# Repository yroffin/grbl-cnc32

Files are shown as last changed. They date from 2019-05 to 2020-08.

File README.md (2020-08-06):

# grbl-cnc32

Simple controller for my RS-CNC32, this Grbl controller runs on a ESP32.

Swagger here : https://yroffin.github.io/grbl-cnc32/swagger-ui

Work based on https://github.com/mstrens/grbl_controller_esp32.

Thanks to https://github.com/mstrens for his initial work.

dependencies
* webui i angular 2.x based (with no CORS enabled).
* ArduinoJson and TFT_eSPI_ms on firmware part

# features and todos

## feature

* firmware
  * move your tools on each axis with TFT or a nunchuk
  * order homing, set coordinate ...
  * get usefull statistics (logs, GRBL output)
  * mount a SDCARD and print your GCODE files
  * handle GRBL admin order (reset, alarm ...)
  * ntp connect to obtain local time
  * wifi and rest server support
    * all configuration handle by api rest (read and write)
    * try a list a access point
  * local serial simulation for developpment
* webui
    * all feature can be reach from this ui
    * graphic positionning
    * load stl files
    * upload gcode files

## todo

* edit gcode directly a sdcard

# api

This firmware is API REST based.

## config.json resource (see bellow in setup bloc)

See https://yroffin.github.io/grbl-cnc32/swagger-ui

# setup and more

see [INSTALL.md](INSTALL.md)

# Hardware and software

## Hardware

To implement this project you need:
- an ESP32 development board and
- a display module combining 3 components:
  - a touch screen 320 X 240 a ILI9341 (display controller),
  - a XPT2046 (control the touch panel) and
  - a SD card support
  
Note: this configuration uses the ILI9341 with 4 wires (CLK, MOSI, MISO and CD).

Currently, this project works only with a TFT having a ILI9341 chip, a resolution of 320X240 and XPT2046 chip for the touch screen. If you are using another display, you should change the code yourself.

## Software

This project compiles in Arduino IDE but it requires:
- to add in Arduino IDE the software that support ESP32. The process is explained e.g. in this link
	https://randomnerdtutorials.com/installing-the-esp32-board-in-arduino-ide-windows-instructions/
 
Take care that if you do not use my configuration, you can have:
-  to edit the file User_setup.h included in the TFT_eSPI_ms folder.
   This file specify the type of display controller and the pins being used by the SPI, the display and the touch screen chip select.
-  to edit the file config.h from this project in order to specify some pins being used (e.g. the chip select for the SD card reader)
  
Note: the pins used for the SPI signals (MOSI, MISO, SCLK) are currently hardcoded.
Please note that many ESP32 pins are reserved and can't ne used (reserved for bootup, for internal flash, input only,...).
See doc on ESP for more details.

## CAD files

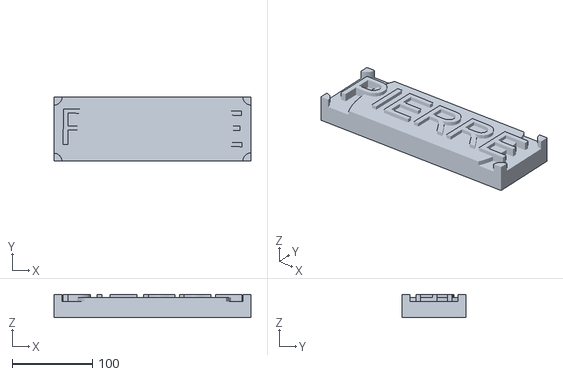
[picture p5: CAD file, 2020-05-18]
ui/src/assets/test.stl
245.2 x 79.9 x 29.0

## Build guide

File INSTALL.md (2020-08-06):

# grbl-cnc32

## Setup arduino

Simply compil and deploy arduino part (vscode plugin is very cool for that)
* see firmware/grbl-cnc32.ino

## Setup ui

In ui folder, simply run npm build (pre-requisite node)

```shell
npm run build
```

And copy dist folder on sdcard in /static

## Setup config

Config sample files are stored in config folder

Simply add a first i18n_enUS.json, i18n_frFR.json on your root SDCARD (it can be updated by API after)

Simply add a first config.json (*) on your root SDCARD (it can be updated by API after)

* remove key tft to force re-calibration

```json
{
    "sys": {
        "lang": "/i18n_enUS.json"
    },
    "wifi": [
        {
            "ssid": "<your SSID>",
            "pass": "<your password>"
        }
    ],
    "tft": {
        "calibrate": [386, 3530, 220, 3627, 7]
    },
    "grbl": {
        "emulate": false
    },
    "nunchuk": {
        "calibrate": {
            "x": 100,
            "y": 100
        }
    },
    "commands": {
        "cmd01": [
            "Line 1",
            "Line 2",
            "..."
        ]
    }
}
```

## wifi bloc

setup your wifi access :
* an array of SSID/PASS to scan

## tft bloc

setup your tft :
* with a 5 values array of tft calibration

## grbl bloc

setup your grbl :
* emulate is a boolean to setup a mock behaviour

## nunchuk bloc

setup your nunchuk :
* calibrate contain 2 fields x and y to setup nunchuk calibration

## commands bloc

setup your commands :
* a lines array for the command

## fingerprint bloc

timestamp
* uTime le last update time in unix second
* fTime le last update time

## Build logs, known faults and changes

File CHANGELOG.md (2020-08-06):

# 1.00

Official 1.00 version after one year of work

# 0.86

Rework command api
- add tryWrite
- add forceWrite
- and reset

# 0.85

Add GRBL file transfer

# 0.84

Write from api (wifi) on console
Add ui

# 0.84

Add webserver feature

# 0.83

Add script capacity in commands

# 0.82

Add command panel
Only handle file in file panel (no more command)
- remove switch
- only print files
Update default calibrate data
Add new widget
- buttonCmd to launch command
- and action control on dialog (for use dialog on other part)

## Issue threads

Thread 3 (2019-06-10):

Enhancement

yroffin, 2019-06-10:
Quelques retours sur ce que je vois: 'up' et 'down' pour Z c'est logique, mais pas pour Y où j'aurais mis 'front' et 'back' (ou un truc du genre, je ne suis pas super bon en anglais).
'Pas'= c'est un mot français au milieu de mots anglais, je trouve ça bizarre, 'step' à la limite (faut qu'un bilingue passe par là, parce que je ne suis pas sûr là non plus).

yroffin, 2019-06-10:
Quelques retours sur ce que je vois: 'up' et 'down' pour Z c'est logique, mais pas pour Y où j'aurais mis 'front' et 'back' (ou un truc du genre, je ne suis pas super bon en anglais).
'Pas'= c'est un mot français au milieu de mots anglais, je trouve ça bizarre, 'step' à la limite (faut qu'un bilingue passe par là, parce que je ne suis pas sûr là non plus).

Closed 2019-06-10.

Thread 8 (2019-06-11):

Work on fusion 360 postprocessor

yroffin, 2019-06-11:
il faut faire son propre post-processor pour corriger les nombreuses erreurs qui sont:
-le %
-le gcode de changement d'outil
-le gcode pour éteindre la broche
-qui inclut le code de Carbide pour avoir des ronds corrects

Closed 2020-05-10.

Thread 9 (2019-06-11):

File display

yroffin, 2019-06-11:
Essai à blanc d'un fichier gcode de la version 8 bits, fonctionnement apparemment OK
Les fichiers .nc de la carte SD n'apparaissent pas dans la liste

yroffin, 2019-06-12:
I've checked ... no bug for me

Closed 2020-05-10.

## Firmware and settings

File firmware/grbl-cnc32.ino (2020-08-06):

#include "TFT_eSPI_ms/TFT_eSPI.cpp" // setup file has to be edited for some parameters like screen device, pins

#include "vars.hpp"
#include "widget.hpp"
#include "evt-ctrl.hpp"
#include "wifi-ctrl.hpp"
#include "storage-ctrl.hpp"
#include "grbl-ctrl.hpp"
#include "i18n-ctrl.hpp"
#include "nunchuk-ctrl.hpp"
#include "json-config.hpp"

void setup()
{
    // prepare TFT
    TFT_Screen::instance()->prepare();

    // JsonConfigCtrl controller
    JsonConfigCtrl::instance()->setup();

    // I18nCtrl controller
    I18nCtrl::instance()->setup();

    // screen controller
    log_i("%s", I18nCtrl::instance()->translate(I18N_STD, "INI", "TFT_Screen"));
    TFT_Screen::instance()->init();

    // event controller
    TFT_Screen::instance()->outputConsole(I18nCtrl::instance()->translate(I18N_STD, "INI", "EvtCtrl"));
    EvtCtrl::instance()->init();

    // storage controller
    TFT_Screen::instance()->outputConsole(I18nCtrl::instance()->translate(I18N_STD, "INI", "StorageCtrl"));
    StorageCtrl::instance()->init();

    // wifi controller
    TFT_Screen::instance()->outputConsole(I18nCtrl::instance()->translate(I18N_STD, "INI", "WifiCtrl"));
    WifiCtrl::instance()->setup();

    // grbl controller
    TFT_Screen::instance()->outputConsole(I18nCtrl::instance()->translate(I18N_STD, "INI", "GrblCtrl"));
    GrblCtrl::instance()->setup();

    // NunchukCtrl controller
    TFT_Screen::instance()->outputConsole(I18nCtrl::instance()->translate(I18N_STD, "INI", "NunchukCtrl"));
    NunchukCtrl::instance()->setup();
}

void loop()
{
    // capture events
    EvtCtrl::instance()->capture();
    // capture events
    NunchukCtrl::instance()->loop();
    // init wifi, capture http request
    WifiCtrl::instance()->loop();
    // flush grbl events
    GrblCtrl::instance()->loop();
    // dispatch event
    EvtCtrl::instance()->dispatchPrimaryEvents();
    // dispatch event (until any)
    for (; EvtCtrl::instance()->dispatchSecondaryEvents();)
        ;
    // render
    TFT_Screen::instance()->render();
    TFT_Screen::instance()->setInvalidated(false);
    // printing
    GrblCtrl::instance()->spool();
    // flush events
    EvtCtrl::instance()->flush();
}

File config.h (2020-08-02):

#ifndef _config_h
#define _config_h

// Note: SPI is currently hardcoded for using following pins
// MOSI=13, MISO=12, SCK=14
// Those are used for the display, the touch panel and the SD card reader.

#define TFT_LED_PIN 25 // pin connected to led of lcd; pin has to be high to set led ON

// other TFT pins are defined in tft_espi User_Setup.h file

#define SD_CHIPSELECT_PIN 26 //5  // pin for SD card selection // to change probably

// pins for Serial to GRBL (it uses Serial2 UART)
#define SERIAL2_RXPIN 16
#define SERIAL2_TXPIN 17

// select color between (or define your own)
// TFT_BLACK       0x0000      /*   0,   0,   0 */
// TFT_NAVY        0x000F      /*   0,   0, 128 */
// TFT_DARKGREEN   0x03E0      /*   0, 128,   0 */
// TFT_DARKCYAN    0x03EF      /*   0, 128, 128 */
// TFT_MAROON      0x7800      /* 128,   0,   0 */
// TFT_PURPLE      0x780F      /* 128,   0, 128 */
// TFT_OLIVE       0x7BE0      /* 128, 128,   0 */
// TFT_LIGHTGREY   0xC618      /* 192, 192, 192 */
// TFT_DARKGREY    0x7BEF      /* 128, 128, 128 */
// TFT_BLUE        0x001F      /*   0,   0, 255 */
// TFT_GREEN       0x07E0      /*   0, 255,   0 */
// TFT_CYAN        0x07FF      /*   0, 255, 255 */
// TFT_RED         0xF800      /* 255,   0,   0 */
// TFT_MAGENTA     0xF81F      /* 255,   0, 255 */
// TFT_YELLOW      0xFFE0      /* 255, 255,   0 */
// TFT_WHITE       0xFFFF      /* 255, 255, 255 */
// TFT_ORANGE      0xFDA0      /* 255, 180,   0 */
// TFT_GREENYELLOW 0xB7E0      /* 180, 255,   0 */
// TFT_PINK        0xFC9F

#define JSON_CONFIG_SIZE 8192
#define JSON_I18N_SIZE 8192

#define SEMVER "v0.86"
#endif

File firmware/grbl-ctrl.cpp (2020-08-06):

#include "ui.hpp"
#include "i18n-ctrl.hpp"
#include "grbl-ctrl.hpp"
#include "storage-ctrl.hpp"
#include "json-config.hpp"
#include "utils.hpp"

// GRBL controller
GrblCtrl *__instance_grbl = 0;

// singleton
GrblCtrl *GrblCtrl::instance()
{
    if (__instance_grbl == 0)
    {
        __instance_grbl = new GrblCtrl();
    }
    return __instance_grbl;
}

GrblCtrl::GrblCtrl()
{
}

void GrblCtrl::setup()
{
    JsonConfigCtrl *jsonConfig = JsonConfigCtrl::instance();
    // stored
    this->stored.mpos.x = 0.;
    this->stored.mpos.y = 0.;
    this->stored.mpos.z = 0.;
    this->stored.wpos.x = 0.;
    this->stored.wpos.y = 0.;
    this->stored.wpos.z = 0.;
    this->stored.grblStatusMetric = true;
    this->stored.grblStatusAbs = true;
    // working
    this->working.mpos.x = 0.;
    this->working.mpos.y = 0.;
    this->working.mpos.z = 0.;
    this->working.wpos.x = 0.;
    this->working.wpos.y = 0.;
    this->working.wpos.z = 0.;
    this->working.grblStatusMetric = true;
    this->working.grblStatusAbs = true;
    // internalSerialBuffer permit alternate byte input (internalSerialBuffer + serial)
    memset(internalSerialBuffer, 0, MAXSIZE_OF_SIM);
    internalSerialIndex = 0;
    internalSerialCounter = 0;
    this->uTime = jsonConfig->getAsInt("fingerprint", "uTime", 0);

    // move
    this->xyzJogPas = jsonConfig->getAsFloat("sys", "speed", "l1", 0.1);
    this->xyzL1Pas = jsonConfig->getAsFloat("sys", "speed", "l1", 0.1);
    this->xyzL2Pas = jsonConfig->getAsFloat("sys", "speed", "l2", 0.5);
    this->xyzL3Pas = jsonConfig->getAsFloat("sys", "speed", "l3", 5);

    strGrblIdx = 0;

    // initialise le port série vers grbl
    Serial2.begin(115200, SERIAL_8N1, SERIAL2_RXPIN, SERIAL2_TXPIN); // initialise le port série vers grbl
    Serial2.print(0X18);                                             // send a soft reset
    Serial2.println(" ");
    Serial2.print("$10=3");
    Serial2.println(" "); // $10=3 is used in order to get available space in GRBL buffer in GRBL status messages; il also means we are asking GRBL to sent always MPos.
    Serial2.flush();      // this is used to avoid sending to many jogging movements when using the nunchuk

    log_i("%s", I18nCtrl::instance()->translate(I18N_STD, "OK", "GRBL"));
}

// Capture serial data
void GrblCtrl::loop(void)
{
    JsonConfigCtrl *jsonConfig = JsonConfigCtrl::instance();
    if (this->uTime != jsonConfig->getAsInt("fingerprint", "uTime", 0))
    {
        this->uTime = jsonConfig->getAsInt("fingerprint", "uTime", 0);
    }

    int c;
    while (available())
    {
        c = read();
        this->byteRead++;
        if (c < 32)
        {
            // control char
            strGrblBuf[strGrblIdx++] = 0;
            flush();
        }
        else
        {
            if (strGrblIdx < STR_GRBL_BUF_MAX_SIZE - 1)
            {
                strGrblBuf[strGrblIdx++] = c;
            }
            else
            {
                // buffer overrun
                strGrblBuf[strGrblIdx++] = 0;
                flush();
            }
        }
    }
    // Update statistics
    TFT_Screen::instance()->statistic->setGrblIo("b: %06d r: %06d w: %06d", this->byteRead, this->txRead, this->txWrite);
}

// Get
void GrblCtrl::getStoredMpos(float *x, float *y, float *z)
{
    *x = this->stored.mpos.x;
    *y = this->stored.mpos.y;
    *z = this->stored.mpos.z;
}

void GrblCtrl::getStoredWpos(float *x, float *y, float *z)
{
    *x = this->stored.wpos.x;
    *y = this->stored.wpos.y;
    *z = this->stored.wpos.z;
}

void GrblCtrl::getStoredModal(bool *metric, bool *abs)
{
    *metric = this->stored.grblStatusMetric;
    *abs = this->stored.grblStatusAbs;
}

void GrblCtrl::getWorkingMpos(float *x, float *y, float *z)
{
    *x = this->working.mpos.x;
    *y = this->working.mpos.y;
    *z = this->working.mpos.z;
}

void GrblCtrl::getWorkingWpos(float *x, float *y, float *z)
{
    *x = this->working.wpos.x;
    *y = this->working.wpos.y;
    *z = this->working.wpos.z;
}

void GrblCtrl::getWorkingModal(bool *metric, bool *abs)
{
    *metric = this->working.grblStatusMetric;
    *abs = this->working.grblStatusAbs;
}

// Simulate a write
void GrblCtrl::serial(const char *message)
{
    /*
    Sample code
    <Idle|MPos:1.000,0.200,0.030|FS:0.0,0|WCO:8.000,0.700,0.006>
    <Jog|WPos:1329.142,0.580,1.000|Bf:32,254|FS:2000,0|Ov:101,102,100|A:FM>
    [Caution: Unlocked]
    error:Modal group violation
    <Idle,MPos:0.000,0.000,0.000,WPos:0.000,0.000,0.000>
    error:20
    */

    memset(internalSerialBuffer, 0, MAXSIZE_OF_SIM);
    sprintf(internalSerialBuffer, "%s\n", message);
    internalSerialIndex = 0;
    internalSerialCounter = strlen(internalSerialBuffer);
    log_i("GRBL: [%s]", message);
}

// Scan new available bytes
int GrblCtrl::available()
{
    // if byte in internalSerialBuffer then use it else read on serial2
    if (internalSerialIndex < internalSerialCounter)
    {
        return 1;
    }
    else
    {
        return Serial2.available();
    }
}

// Read one byte
int GrblCtrl::read()
{
    // consume all bytes in internalSerialIndex before reading on serial
    if (internalSerialIndex < internalSerialCounter)
    {
        return internalSerialBuffer[internalSerialIndex++];
    }
    else
    {
        return Serial2.read();
    }
}

// write
void GrblCtrl::write(boolean flush, const char *value)
{
    // write data
    Serial2.print(value);
    // wait for send all data
    if (flush)
        Serial2.flush();
    TFT_Screen::instance()->menu->status->notifyWrite((uint16_t)strlen(value));
}

void GrblCtrl::setBusy(boolean _busyState)
{
    this->busy = _busyState;
    TFT_Screen::instance()->menu->status->notifyBusy(this->busy);
}

boolean GrblCtrl::isBusy()
{
    return this->busy;
}

// string function
bool startWithNoCase(const char *str, const char *pattern)
{
    bool status = false;
    return status;
}

boolean match(const char *pattern, const char *value)
{
    return strncmp(pattern, value, strlen(pattern)) == 0;
}
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

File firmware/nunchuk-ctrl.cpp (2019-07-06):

#include "nunchuk-ctrl.hpp"
#include "grbl-ctrl.hpp"
#include "evt-ctrl.hpp"
#include "json-config.hpp"

// NunchukCtrl controller
NunchukCtrl *__instance_NunchukCtrl = 0;

// singleton
NunchukCtrl *NunchukCtrl::instance()
{
    if (__instance_NunchukCtrl == 0)
    {
        __instance_NunchukCtrl = new NunchukCtrl();
    }
    return __instance_NunchukCtrl;
}

NunchukCtrl::NunchukCtrl()
{
}

void NunchukCtrl::setup()
{
    JsonConfigCtrl *jsonConfig = JsonConfigCtrl::instance();
    this->xcenter = jsonConfig->getAsInt("nunchuk", "calibrate", "x", 134);
    this->ycenter = jsonConfig->getAsInt("nunchuk", "calibrate", "y", 134);
    this->uTime = jsonConfig->getAsInt("fingerprint", "uTime", 0);

    this->xyzL1Pas = jsonConfig->getAsFloat("nunchuk", "speed", "l1", 0.1);
    this->xyzL2Pas = jsonConfig->getAsFloat("nunchuk", "speed", "l2", 5.0);
}

void NunchukCtrl::loop()
{
    JsonConfigCtrl *jsonConfig = JsonConfigCtrl::instance();
    if (jsonConfig->getAsInt("fingerprint", "uTime", 0) != this->uTime)
    {
        this->xcenter = jsonConfig->getAsInt("nunchuk", "calibrate", "x", 134);
        this->ycenter = jsonConfig->getAsInt("nunchuk", "calibrate", "y", 134);
        this->uTime = jsonConfig->getAsInt("fingerprint", "uTime", 0);
    }
    switch (this->state)
    {
    case NUNCHUK_STATE_ZERO:
        Wire.begin();
        // Change TWI speed for nunchuk, which uses Fast-TWI (400kHz)
        // Normally this will be set in twi_init(), but this hack works without modifying the original source
        Wire.setClock(400000);
        this->wait = millis();
        this->state = NUNCHUK_STATE_WAIT;
        break;
    case NUNCHUK_STATE_WAIT:
        if (millis() - this->wait > 500)
        {
            this->wait = millis();
            this->state = NUNCHUK_STATE_INIT;
        }
        break;
    case NUNCHUK_STATE_INIT:
        Wire.beginTransmission(NUNCHUK_ADDRESS);
        if (Wire.endTransmission())
        {
            this->state = NUNCHUK_KO;
        }
        else
        {
            this->wait = millis();
            this->state = NUNCHUK_STATE_CAN_READ;
        }
        break;
    case NUNCHUK_STATE_CAN_READ:
        disableEncription();
        read();
        delay(20);
        this->wait = millis();
        this->state = NUNCHUK_STATE_START_READ;
        break;
    case NUNCHUK_STATE_START_READ:
        if (!read())
        {
            break;
        }
        this->wait = millis();
        this->state = NUNCHUK_OK;

        {
            // save current state
            boolean current_z = this->z;
            boolean current_c = this->c;
            int16_t current_xplane = this->xplane;
            int16_t current_yplane = this->yplane;

            // new state
            this->z = Z();
            this->c = C();

            // raw value
            if (this->xplane != (nunchuk_data[0] - this->xcenter) || this->yplane != (nunchuk_data[1] - this->ycenter))
            {
                this->xplane = nunchuk_data[0] - this->xcenter;
                this->yplane = nunchuk_data[1] - this->ycenter;
            }

            // check change on Z and C
            if (current_z != z)
            {
                EvtCtrl::instance()->sendInt(WIDGET_ID_DEFAULT, NUNCHUK_Z, z);
            }

            if (current_c != c)
            {
                EvtCtrl::instance()->sendInt(WIDGET_ID_DEFAULT, NUNCHUK_C, c);
            }

            // check change on xplane and yplane
            if (current_xplane != xplane || current_yplane != yplane)
            {
                EvtCtrl::instance()->sendTouch(WIDGET_ID_DEFAULT, NUNCHUK_DATA, xplane, yplane);
            }

            // lader value
            if (c && !z)
            {
                if (abs(xplane) >= 10 || abs(yplane) >= 10)
                {
                    float xlader = abs(xplane) < 10 ? 0. : abs(xplane) < 60 ? this->xyzL1Pas : this->xyzL2Pas;
                    float ylader = abs(yplane) < 10 ? 0. : abs(yplane) < 60 ? this->xyzL1Pas : this->xyzL2Pas;
                    GrblCtrl::instance()->jogMoveXY(xplane < 0 ? -xlader : xlader, yplane < 0 ? -ylader : ylader);
                }
            }

            if (!c && z)
            {
                if (abs(yplane) >= 10)
                {
                    float ylader = abs(yplane) < 10 ? 0. : abs(yplane) < 60 ? this->xyzL1Pas : this->xyzL2Pas;
                    GrblCtrl::instance()->jogMoveZ(yplane < 0 ? -ylader : ylader);
                }
            }
        }
        break;

    case NUNCHUK_OK:
        if (millis() - this->wait > 20)
        {
            this->wait = millis();
            this->state = NUNCHUK_STATE_START_READ;
        }
        break;

    case NUNCHUK_KO:
        break;
    }
}

void NunchukCtrl::disableEncription()
{
    I2C_START(NUNCHUK_ADDRESS); // disable encription with next 2 commands
    I2C_WRITE(0xF0);
    I2C_WRITE(0x55);
    I2C_STOP();
    I2C_START(NUNCHUK_ADDRESS);
    I2C_WRITE(0xFB);
    I2C_WRITE(0x00);
    I2C_STOP();
}

boolean NunchukCtrl::read()
{
    uint8_t i;
    uint8_t error = 0;
    Wire.requestFrom(NUNCHUK_ADDRESS, 6);
    for (i = 0; i < 6 && Wire.available(); i++)
    {
        nunchuk_data[i] = I2C_READ();
        if (nunchuk_data[i] == 0 || nunchuk_data[i] == 0xFF)
        {
            error |= (1 << i);
        }
    }
    // error when all received bytes are 00 or FF.
    if (error == 0b00111111)
    {
        disableEncription(); // try to reactivate nunchunck in case of error.
    }
    I2C_START(NUNCHUK_ADDRESS);
    I2C_WRITE(0x00);
    I2C_STOP();
    return !(error == 0b00111111); // return true when there is no error
}

boolean NunchukCtrl::Z()
{ // Checks the current state of button Z
    return (~nunchuk_data[5]) & 1 == 1;
}

boolean NunchukCtrl::C()
{ // Checks the current state of button C
    return (~nunchuk_data[5] >> 1) & 1 == 1;
}

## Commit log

2019-05-12 Initial revision
    [Configuring options.txt]
2019-05-18 Add GRBL status
2019-05-18 Rework display and grbl write
    [grbl-cnc32.ino, grbl-ctrl.cpp]
2019-05-22 Add printing
2019-05-25 Correct MPOS and error handling
    [grbl-cnc32.ino, grbl-ctrl.cpp]
2019-06-02 Add print stats
2019-06-03 Add calibration parameters for nunchuk
2019-06-05 Store calibrate configuration
2019-06-06 Rework on file access
    [grbl-cnc32.ino, grbl-ctrl.cpp, nunchuk-ctrl.cpp]
2019-06-10 Change nunchuk error detection
    [nunchuk-ctrl.cpp]
2019-06-10 Enhance print display
2019-06-10 Grbl mock
2019-06-11 Print message while waiting for SD
2019-06-13 Add print dialog
2019-07-21 Fix/commands (#16)
    * Rework on files and commands
    [config.h]
2019-07-28 Fix/probe (#17)
    * Capture units and coordinates
    * Add script behaviour
    * swagger
    * Add script behaviour
    [config.h, grbl-ctrl.cpp]
2020-05-10 Fix/probe (#19)
    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
2020-05-18 Feat/next01 (#24)
    * Update
    * Update
    * Update
    * Add ui
    [test.stl]
2020-08-01 Add fie api (#32)
    * Add file api
    * Add STL reader
2020-08-02 Update gestion des fichiers (#35)
2020-08-02 Mise à jour des envois de commandes (#36)
2020-08-02 Ajout de la simulation (#37)
2020-08-06 Fix bug printing (#38)
    [grbl-ctrl.cpp]
2020-08-06 Rework (#39)
    [Configuring options.txt]
